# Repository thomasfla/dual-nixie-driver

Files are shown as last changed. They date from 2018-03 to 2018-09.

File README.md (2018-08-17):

# dual-nixie-driver

A simple board, driving 2 nixies from discrete transistors and a Atmega8.
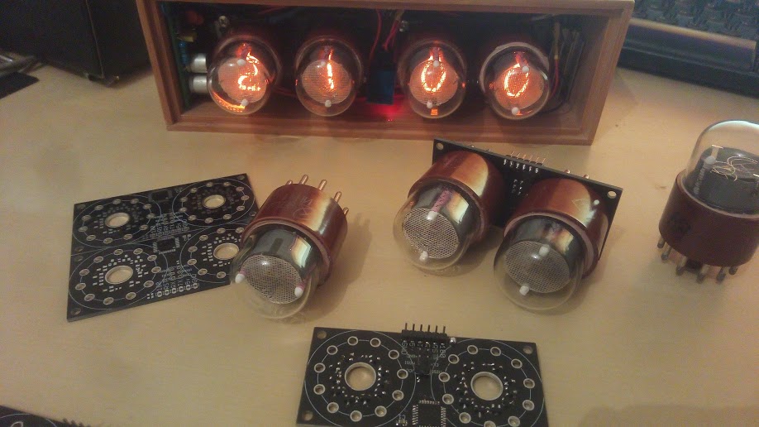
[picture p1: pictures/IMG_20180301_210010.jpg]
Nixie


# Licence 
This all project is under (CC BY-SA 3.0) licence in the Open Source Hardware spirit https://www.oshwa.org/
All help or comment are wellcome; 
See more here https://hackaday.io/project/69708

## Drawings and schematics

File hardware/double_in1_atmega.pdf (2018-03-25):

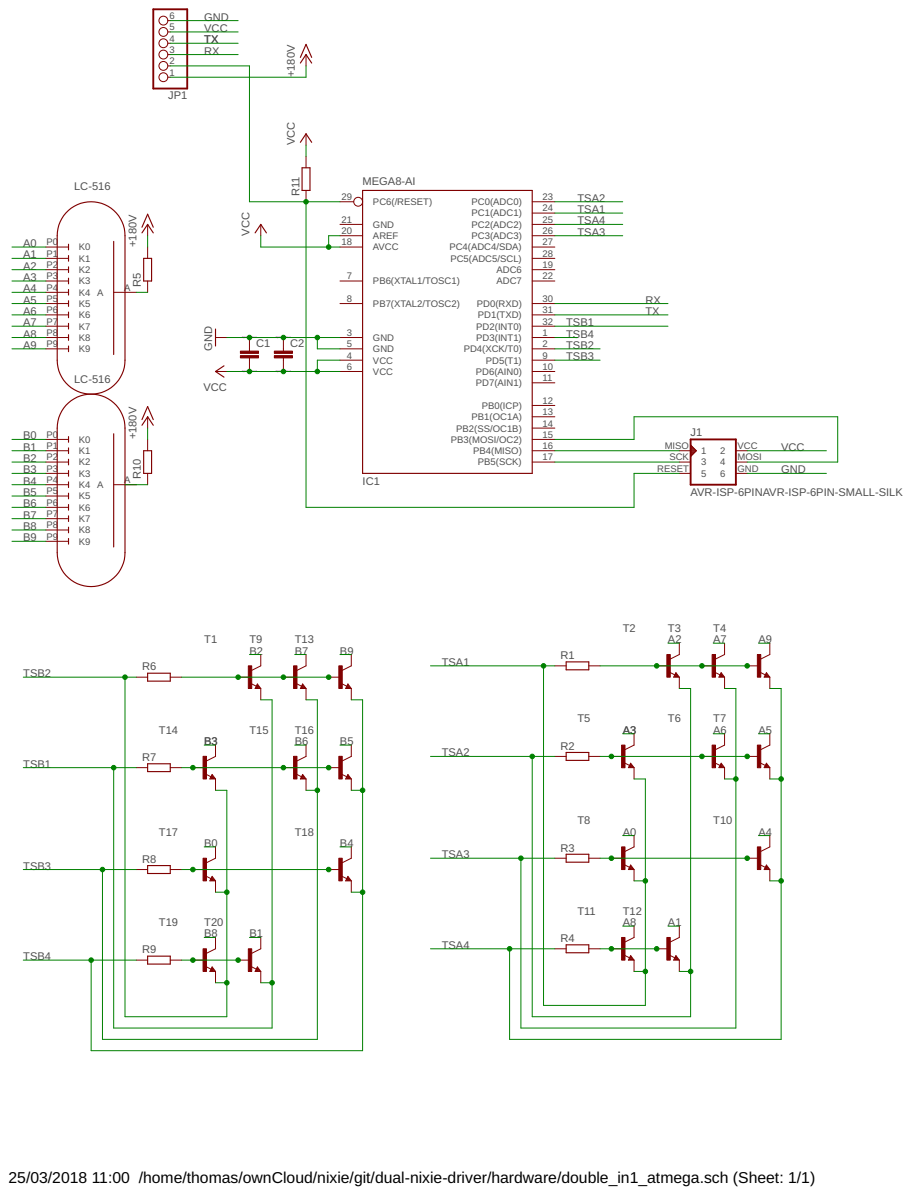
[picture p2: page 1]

AVR-ISP-6PINAVR-ISP-6PIN-SMALL-SILK

25/03/2018 11:00 /home/thomas/ownCloud/nixie/git/dual-nixie-driver/hardware/double_in1_atmega.sch (Sheet: 1/1)

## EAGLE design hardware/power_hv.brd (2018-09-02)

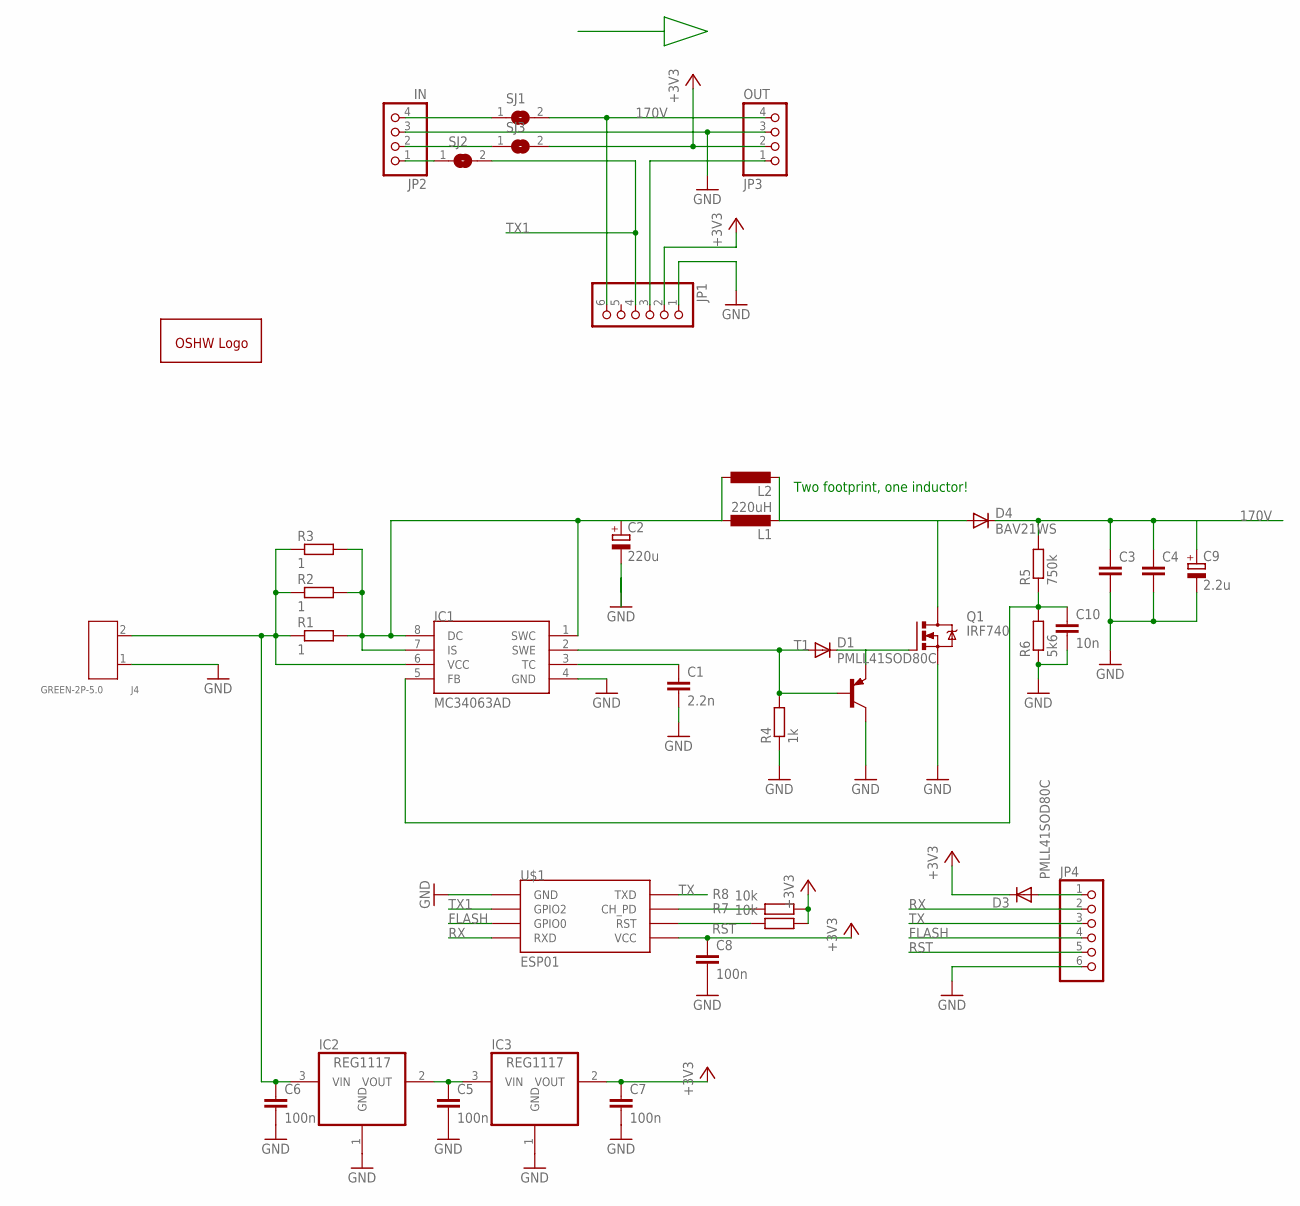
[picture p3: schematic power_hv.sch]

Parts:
C1: 2.2n; C0805
C2: 220u; 140CLH-0810
C3, C4: C-EUC1210K; C1210K
C5, C6, C7, C8: 100n; C0805
C9: 2.2u; E5-8,5
C10: 10n; C0805
D1, D3: PMLL41SOD80C; SOD80C
D4: BAV21WS; SOD323-W
GOLD_ORB_SM1: OSHWLOGOLOGO8MM; OSHW_8MM
IC1: MC34063AD; SOIC8
IC2, IC3: REG1117; SOT223
J4: GREEN-2P-5.0; H2-5.0-10.5X8.0MM
JP1, JP4: PINHD-1X6; 1X06
JP2: IN; 1X04
JP3: OUT; 1X04
L1: 220uH; POWER-CHOKE_WE-TPC
L2: L-EU6000-XXX-RC; 6000-XXXX-RC
Q1: IRF740; TO220BV
R1, R2, R3: 1; R0805
R4: 1k; R0805
R5: 750k; R0805
R6: 5k6; R0805
R7, R8: 10k; R0805
SJ1, SJ2, SJ3: SJ
T1: BC807-40-PNP-SOT23-BEC; SOT23-BEC
U$1: ESP01

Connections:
170V: C3.1, C4.1, C9.+, D4.C, JP1.6, JP3.4, R5.2, SJ1.2
+3V3: C7.1, C8.1, D3.C, IC3.2 (VOUT), JP1.2, JP3.2, R7.1, R8.1, SJ3.2, U$1.VCC
FLASH: JP4.4, U$1.GPIO0
GND: C1.2, C2.-, C3.2, C4.2, C5.2, C6.2, C7.2, C8.2, C9.-, C10.2, IC1.4 (GND), IC2.1 (GND), IC3.1 (GND), J4.1, JP1.1, JP2.3, JP3.3, JP4.6, Q1.S, R4.1, R6.1, T1.C, U$1.GND
unnamed: C2.+, IC1.1 (SWC), IC1.7 (IS), IC1.8 (DC), L1.1, L2.1, R1.2, R2.2, R3.2
unnamed: D1.A, IC1.2 (SWE), R4.2, T1.B
unnamed: C1.1, IC1.3 (TC)
unnamed: JP1.3, JP3.1
unnamed: C6.1, IC1.6 (VCC), IC2.3 (VIN), J4.2, R1.1, R2.1, R3.1
unnamed: D1.C, Q1.G, T1.E
unnamed: D4.A, L1.2, L2.2, Q1.D
unnamed: C10.1, IC1.5 (FB), R5.1, R6.2
unnamed: C5.1, IC2.2 (VOUT), IC3.3 (VIN)
unnamed: R8.2, U$1.CH_PD
unnamed: D3.A, JP4.1
unnamed: JP2.4, SJ1.1
unnamed: JP2.2, SJ3.1
unnamed: JP2.1, SJ2.1
RST: JP4.5, R7.2, U$1.RST
RX: JP4.2, U$1.RX (RXD)
TX: JP4.3, U$1.TX (TXD)
TX1: JP1.4, SJ2.2, U$1.GPIO2

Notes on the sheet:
Two footprint, one inductor!

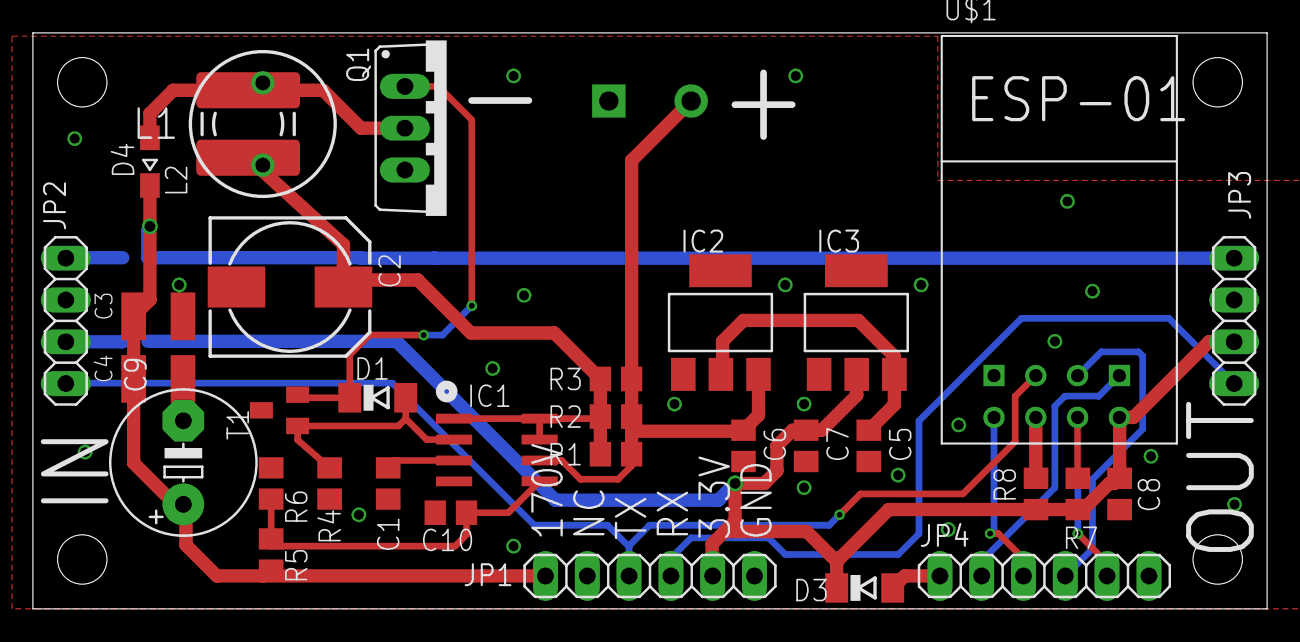
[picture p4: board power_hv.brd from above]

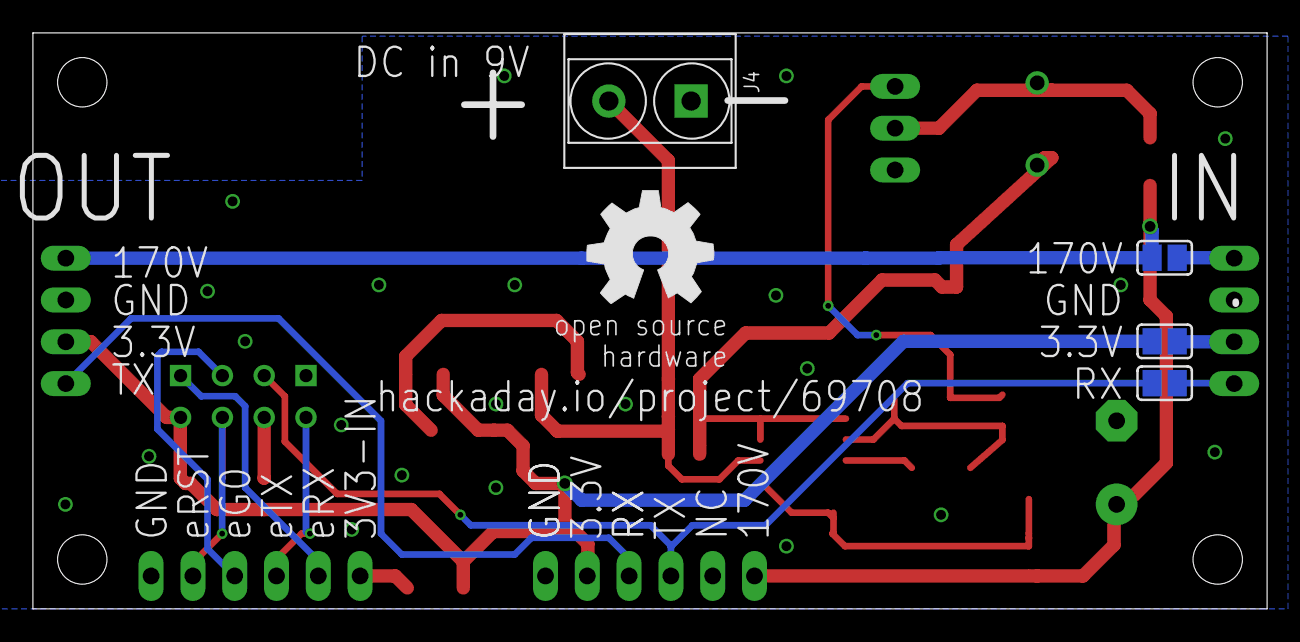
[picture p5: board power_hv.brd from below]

Board: 2 copper layers, 75.0 x 35.0 mm, 38 parts (5 on the bottom side), 22 nets.

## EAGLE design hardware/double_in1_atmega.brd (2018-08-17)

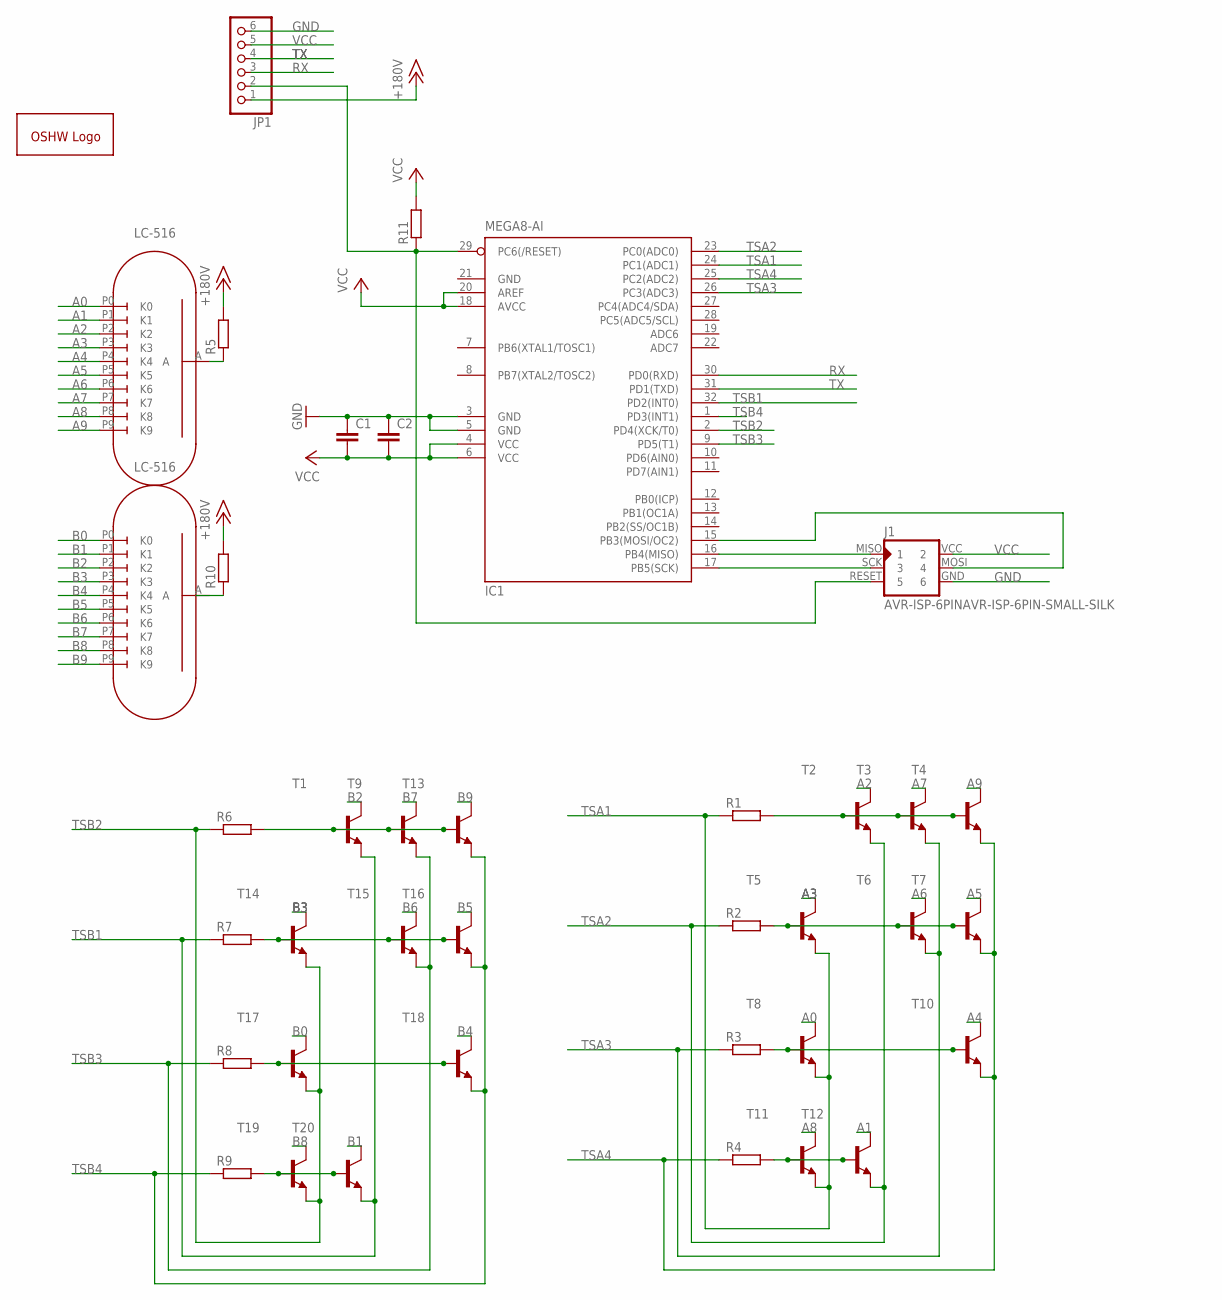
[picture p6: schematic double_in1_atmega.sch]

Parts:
C1, C2: C; C0805
GOLD_ORB_SM1: OSHWLOGOLOGO5MM; OSHW_5MM
IC1: MEGA8-AI; TQFP32-08
J1: AVR-ISP-6PINAVR-ISP-6PIN-SMALL-SILK; AVR-ISP-6PIN-SMAILL-SILK
JP1: PINHD-1X6; 1X06
R1, R2, R3, R4, R6, R7, R8, R9, R11: R-EU_R0603; R0603
R5, R10: R-EU_M1206; M1206
T1, T2, T3, T4, T5, T6, T7, T8, T9, T10, T11, T12, T13, T14, T15, T16, T17, T18, T19, T20: MMBTA42LT1-NPN-SOT23-BEC; SOT23-BEC
U$1, U$2: LC-516

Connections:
+15V: JP1.1, R5.2, R10.2
A0: T8.C, U$1.P0 (K0)
A1: T12.C, U$1.P1 (K1)
A2: T2.C, U$1.P2 (K2)
A3: T5.C, U$1.P3 (K3)
A4: T10.C, U$1.P4 (K4)
A5: T7.C, U$1.P5 (K5)
A6: T6.C, U$1.P6 (K6)
A7: T3.C, U$1.P7 (K7)
A8: T11.C, U$1.P8 (K8)
A9: T4.C, U$1.P9 (K9)
B0: T17.C, U$2.P0 (K0)
B1: T20.C, U$2.P1 (K1)
B2: T1.C, U$2.P2 (K2)
B3: T14.C, U$2.P3 (K3)
B4: T18.C, U$2.P4 (K4)
B5: T16.C, U$2.P5 (K5)
B6: T15.C, U$2.P6 (K6)
B7: T9.C, U$2.P7 (K7)
B8: T19.C, U$2.P8 (K8)
B9: T13.C, U$2.P9 (K9)
GND: C1.1, C2.1, IC1.3 (GND), IC1.5 (GND), IC1.21 (GND), J1.GND (6), JP1.6
unnamed: R10.1, U$2.A
unnamed: IC1.29 (PC6(/RESET)), J1.RESET (5), JP1.2, R11.1
unnamed: R5.1, U$1.A
unnamed: IC1.16 (PB4(MISO)), J1.MISO (1)
unnamed: IC1.17 (PB5(SCK)), J1.SCK (3)
unnamed: IC1.15 (PB3(MOSI/OC2)), J1.MOSI (4)
unnamed: R6.2, T1.B, T9.B, T13.B
unnamed: R9.2, T19.B, T20.B
unnamed: R7.2, T14.B, T15.B, T16.B
unnamed: R4.2, T11.B, T12.B
unnamed: R8.2, T17.B, T18.B
unnamed: R3.2, T8.B, T10.B
unnamed: R2.2, T5.B, T6.B, T7.B
unnamed: R1.2, T2.B, T3.B, T4.B
RX: IC1.30 (PD0(RXD)), JP1.3
TSA1: IC1.24 (PC1(ADC1)), R1.1, T5.E, T8.E, T11.E
TSA2: IC1.23 (PC0(ADC0)), R2.1, T2.E, T12.E
TSA3: IC1.26 (PC3(ADC3)), R3.1, T3.E, T6.E
TSA4: IC1.25 (PC2(ADC2)), R4.1, T4.E, T7.E, T10.E
TSB1: IC1.32 (PD2(INT0)), R7.1, T1.E, T20.E
TSB2: IC1.2 (PD4(XCK/T0)), R6.1, T14.E, T17.E, T19.E
TSB3: IC1.9 (PD5(T1)), R8.1, T9.E, T15.E
TSB4: IC1.1 (PD3(INT1)), R9.1, T13.E, T16.E, T18.E
TX: IC1.31 (PD1(TXD)), JP1.4
VCC: C1.2, C2.2, IC1.4 (VCC), IC1.6 (VCC), IC1.18 (AVCC), IC1.20 (AREF), J1.VCC (2), JP1.5, R11.2

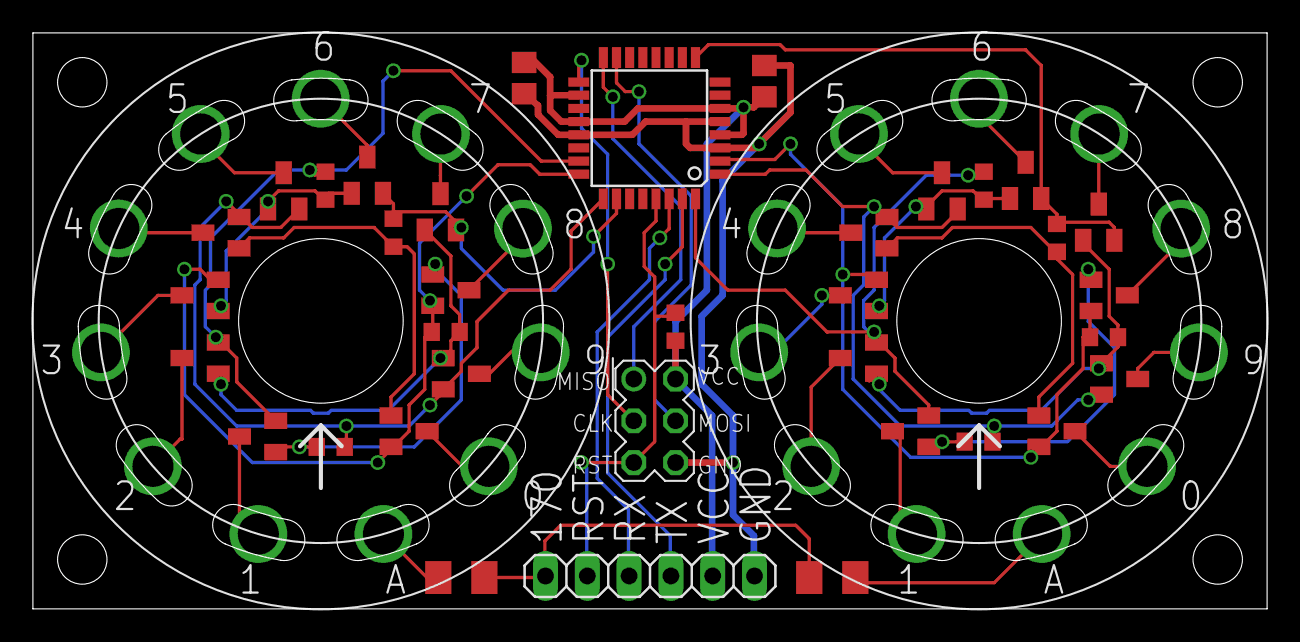
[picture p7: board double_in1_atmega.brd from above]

Board: 2 copper layers, 75.0 x 35.0 mm, 39 parts (1 on the bottom side), 47 nets.

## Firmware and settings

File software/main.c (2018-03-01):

#include <avr/io.h>
#define F_CPU 8000000UL
#include <util/delay.h>
#define LED_PIN PB5
#define TX_PIN PD1
#define BAUD 9600                               	// define baud (9600:0.2%error)
#define BAUDRATE ((F_CPU)/(BAUD*16UL)-1)        	// set baud rate value for UBRR

#define sbi(port, bit) (port) |= (1 << (bit))
#define cbi(port, bit) (port) &= ~(1 << (bit))
#define TSA1 1 // PC1 
#define TSA2 0 // PC0
#define TSA3 3 // PC3
#define TSA4 2 // PC2

#define TSB1 4 // PD4
#define TSB2 2 // PD2
#define TSB3 5 // PD5
#define TSB4 3 // PD3
/*
noxtal @8MHz
avrdude -c usbasp -p m8 -U lfuse:w:0xE4:m -U hfuse:w:0xC4:m
*/

// function to initialize UART
void uart_init (void)
{
    UBRRH = (BAUDRATE>>8);
    UBRRL = BAUDRATE;                       	// set baud rate
    UCSRB|= (1<<TXEN)|(1<<RXEN);            	// enable RX and TX
    UCSRC|= (1<<URSEL)|(1<<UCSZ0)|(1<<UCSZ1);   // 8bit data format
}
//~ int setup(void);
int setup(void)
{
  /* Set LED_PIN to output. */
  //~ DDRB |= _BV(LED_PIN);  
  //~ DDRD |= _BV(TX_PIN);  
  
  uart_init();
  return 0;	
}

// function to send data
void uart_transmit (unsigned char data)
{
    while (!( UCSRA & (1<<UDRE)));            	// wait while register is free
    UDR = data;                               	// load data in the register
}
// function to receive data
unsigned char uart_received (void)
{
    while(!((UCSRA) & (1<<RXC)));               	// wait while data is being received
    return UDR;                               	// return 8-bit data
}

void set_to_1 (unsigned char *port,unsigned char *ddr,unsigned char bit)
{
  sbi(*ddr , bit); // output
  sbi(*port, bit); // 1
}
void set_to_0 (unsigned char *port,unsigned char *ddr,unsigned char bit)
{
  sbi(*ddr , bit); // output
  cbi(*port, bit); // 0
}
void set_to_Z (unsigned char *port,unsigned char *ddr,unsigned char bit)
{
  cbi(*ddr , bit); // input
  cbi(*port, bit); // no pull-up
}
void display_n(unsigned char n, unsigned char AB)
{
    unsigned char DDR  = (AB)?DDRC:DDRD;   //make a copy of current I/O register value
    unsigned char PORT = (AB)?PORTC:PORTD; //make a copy of current I/O register value
    unsigned char TS1  = (AB)?TSA1:TSB1;
    unsigned char TS2  = (AB)?TSA2:TSB2;
    unsigned char TS3  = (AB)?TSA3:TSB3;
    unsigned char TS4  = (AB)?TSA4:TSB4;
    //default all Z
    set_to_Z(&PORT,&DDR,TS1);
    set_to_Z(&PORT,&DDR,TS2);
    set_to_Z(&PORT,&DDR,TS3);
    set_to_Z(&PORT,&DDR,TS4);
    switch(n) {
        case 0:
          set_to_1(&PORT,&DDR,TS3);
          set_to_0(&PORT,&DDR,TS1);
        break; 
        case 1:
          set_to_1(&PORT,&DDR,TS4);
          set_to_0(&PORT,&DDR,TS2);
        break; 
        case 2:
          set_to_1(&PORT,&DDR,TS1);
          set_to_0(&PORT,&DDR,TS2);
        break; 
        case 3:
          set_to_1(&PORT,&DDR,TS2);
          set_to_0(&PORT,&DDR,TS1);
        break; 
        case 4:
          set_to_1(&PORT,&DDR,TS3);
          set_to_0(&PORT,&DDR,TS4);
        break; 
        case 5:
          set_to_1(&PORT,&DDR,TS2);
          set_to_0(&PORT,&DDR,TS4);
        break; 
        case 6:
          set_to_1(&PORT,&DDR,TS2);
          set_to_0(&PORT,&DDR,TS3);
        break; 
        case 7:
          set_to_1(&PORT,&DDR,TS1);
          set_to_0(&PORT,&DDR,TS3);
        break; 
        case 8:
          set_to_1(&PORT,&DDR,TS4);
          set_to_0(&PORT,&DDR,TS1);
        break; 
        case 9:
          set_to_1(&PORT,&DDR,TS1);
          set_to_0(&PORT,&DDR,TS4);
        break;
	case 10:
		//This is all off
	break;  
        default:
          set_to_1(&PORT,&DDR,TS3);
          set_to_0(&PORT,&DDR,TS1);
    }
    if (AB)  //apply I/O register value
    {
        DDRC = DDR;
        PORTC = PORT;
    }
    else
    {
        DDRD = DDR;
        PORTD = PORT;
    }
}

int main(void)
{	
	// setup
	setup();

    //test display 00 11 22 33 ..
    int i,j,k;

    //~ display_n(10,0);
	//~ while(1) // Dimming
	//~ {
		//~ for (j=0;j<50;j++)
		//~ {
			//~ for (i=0;i<10;i++)
			//~ {
				//~ for (k=0;k<50;k++)
				//~ {
					//~ if (k<j)
					 //~ {display_n(5,1);}
					//~ else
					 //~ {display_n(10,1);}
				//~ }
				//~ _delay_ms(1); 
			//~ }
		//~ }
		//~ for (j=0;j<50;j++)
		//~ {
			//~ for (i=0;i<10;i++)
			//~ {
				//~ for (k=0;k<50;k++)
				//~ {
					//~ if (k<j)
					 //~ {display_n(10,1);}
					//~ else
					 //~ {display_n(5,1);}
				//~ }
				//~ _delay_ms(1); 
			//~ }
		//~ }
	//~ }

    for (i=0;i<10;i++)
    {
        display_n(i,0);
        display_n(i,1);
        _delay_ms(500); 
    }

    for (i=0;i<100;i++)
    {
        display_n(i/10,0);
        display_n(i%10,1);
        _delay_ms(100); 
    }

	//daisy chain BCD format ends with 0xff
	// example: 12h30m59s will be:
	//      0x12 0x30 0x59 0xff
	// if this board is the first, it will transmit 
    //      0x12 0x30 0xff
    // and will display 
    //      (5)(9) 
    unsigned char rx_prev=0xf0; //0xf0 is a reserved value meaning empty
    unsigned char rx=0xf0; 
    while(1) 
    {
        rx_prev = rx;
        rx=uart_received();
        if (rx == 0xff) //it is the end
        { 
            uart_transmit(0xff);
            display_n((rx_prev>>4)&0x0F,0);
            display_n((rx_prev   )&0x0F,1);
            rx=0xf0;
        }
        else if(rx_prev!=0xf0)
        {
            uart_transmit(rx_prev);
        }
    }
	return 0;
}

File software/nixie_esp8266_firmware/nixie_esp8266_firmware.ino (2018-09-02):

#include <ESP8266WiFi.h>          //https://github.com/esp8266/Arduino
#include <DNSServer.h>
#include <ESP8266WebServer.h>
#include <WiFiManager.h>         //https://github.com/tzapu/WiFiManager
#include <time.h>
#include <EEPROM.h>

char timeZone[6] = "1";
int i=0;
int8_t tz = 1;
WiFiManagerParameter custom_timeZone("timeZone", "UTC+", timeZone, 6);
WiFiManager wifiManager;

void setup() {
    Serial.begin(9600);
    Serial1.begin(9600);
    EEPROM.begin(1);
    tz=EEPROM.read(0);
    sprintf(timeZone,"%d",tz);
    Serial.printf("tz_eeprom: %d\r\n",tz);
    custom_timeZone.setValue(timeZone, 6);
    WiFi.persistent(true);
    WiFi.mode(WIFI_STA);
    WiFi.begin();
    wifiManager.setDebugOutput(1);
    wifiManager.setSaveConfigCallback(saveConfigCallback);
    wifiManager.addParameter(&custom_timeZone);
    wifiManager.setTimeout(30);
    wifiManager.setConfigPortalBlocking(false);
    Serial.println("Going to open a WIFI access point for user configuration, closing in 30s! SSID:NixieClockConfig");
    wifiManager.startConfigPortal("NixieClockConfig");
}

void saveConfigCallback () {
  Serial.println("Save new TimeZone setting");
  String inString = custom_timeZone.getValue();
  tz = inString.toInt();
  EEPROM.write(0,tz);
  EEPROM.commit();
}

unsigned char decToBCD(unsigned char dec) {
    return (dec / 10 << 4) + dec%10;  
}

void loop() {
    time_t now = time(nullptr);
    //Serial.println(ctime(&now));
    tm* time_tm = localtime(&now);
    if (i%10 == 0 || time_tm->tm_year < 100) {
      //Serial.println("Update time via NTP");
      configTime(tz * 3600, 0, "pool.ntp.org", "time.nist.gov");
    }
    wifiManager.process();
    Serial.write(decToBCD(time_tm->tm_hour));
    Serial1.write(decToBCD(time_tm->tm_hour));
    delay(10);
    Serial.write(decToBCD(time_tm->tm_min));
    Serial1.write(decToBCD(time_tm->tm_min));
    delay(10);
    Serial.write(0xff); //end of packet
    Serial1.write(0xff); //end of packet
    delay(500);
    i++;
}

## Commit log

2018-03-25 [PCB] rev1; Change resistors size, center ATMEGA8, make slots for nixie alignment, minor changes
    [double_in1_atmega.brd, double_in1_atmega.sch, double_in1_atmega_pannelized.brd]
2018-08-17 add optional master board with esp8266 to drive the module and with 170V power supply
    [power_hv.brd, power_hv.sch]
2018-08-17 generate gerber for jlpcb
    [double_in1_atmega.brd, double_in1_atmega.sch, double_in1_atmega_pannelized.brd]
2018-08-17 remove manualy panelize version since jlpcb does it for free
    [double_in1_atmega_pannelized.brd]
2018-09-02 send on the two serials for compatibility with new board design
2018-09-02 set component values; add filter cap on power feedback
    [power_hv.brd, power_hv.sch]
